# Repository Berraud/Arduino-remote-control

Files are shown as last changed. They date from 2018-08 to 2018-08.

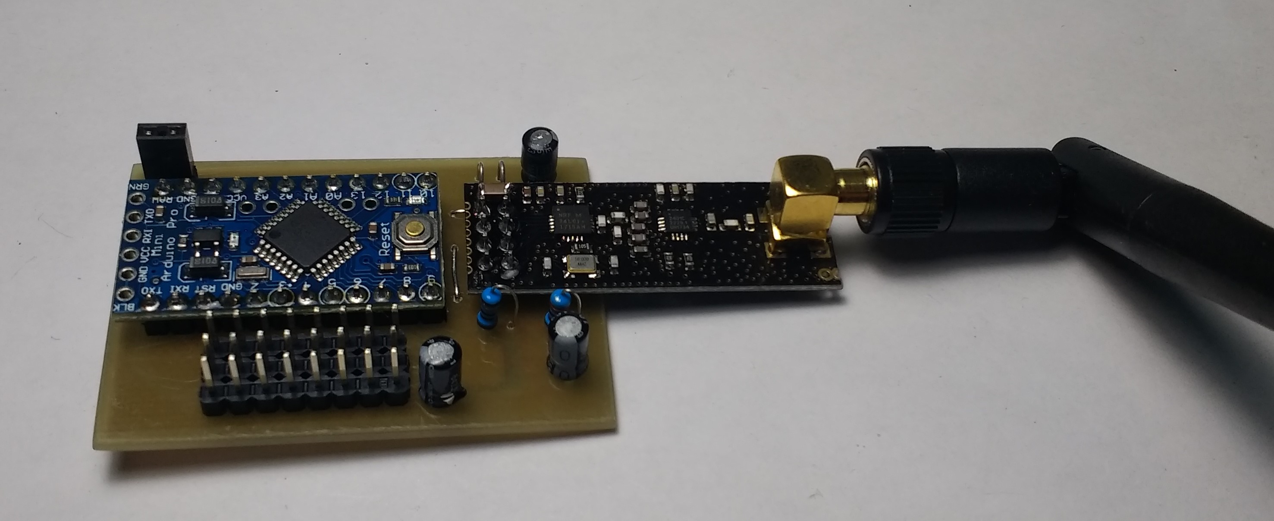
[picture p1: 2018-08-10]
PCB/RX.jpg

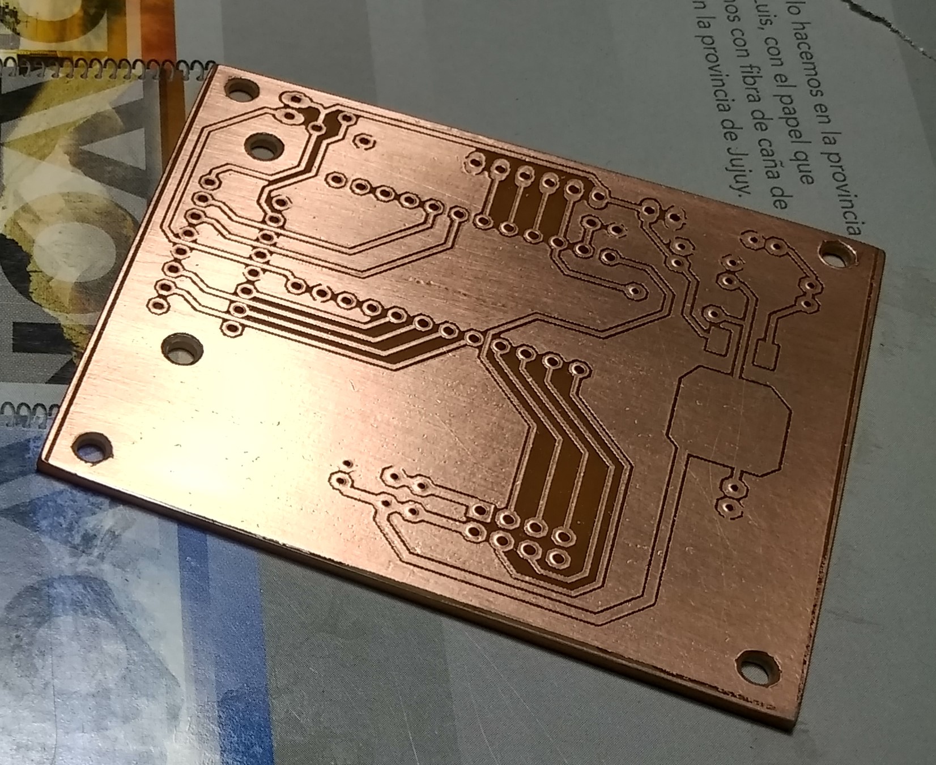
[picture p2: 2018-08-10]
PCB/Txb.jpg

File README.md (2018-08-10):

# Arduino-remote-control
Arduino based multi channel remote control for aeromodelism with telemetry and PS2 controller.
Based on arduino pro mini and NRF20L01 modules. Uses a PS2 remote controller as input.
Features multiple channels and memory for saving multiple models. Dual rates, throttle cut, on-fly default position set up (in case of signal lost), telemetry for measuring remote battery voltage and some other things.
If you have any questions email me to simonb2230@gmail.com

Based on a few nice projects from:
http://www.billporter.info/2010/06/05/playstation-2-controller-arduino-library-v1-0/
https://www.flitetest.com/articles/custom-arduino-2-4ghz-rc-transmitter
http://www.electronoobs.com/eng_robotica_tut5_2_1.php

and probably some other examples that I can't remember.

The power for the remote is from a single LiIon battery from a portable charger (using the same charging circuit)
The power for the receiver comes from the BEC of the ESC. The resistive divider on the receiver is calculated for a 3S Lipo battery.

The NRF modules need a 1uf ceramic SMD cap soldered directly on the PCB of the module itself

The range tested on ground is about 800m

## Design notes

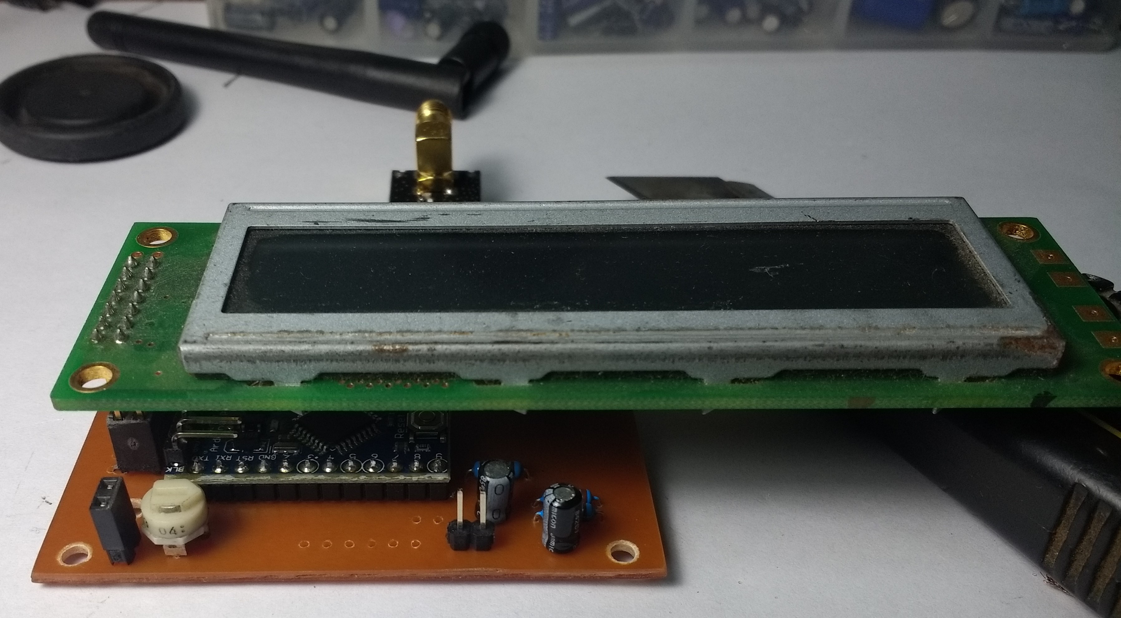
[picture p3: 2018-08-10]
PCB/Tx.jpg

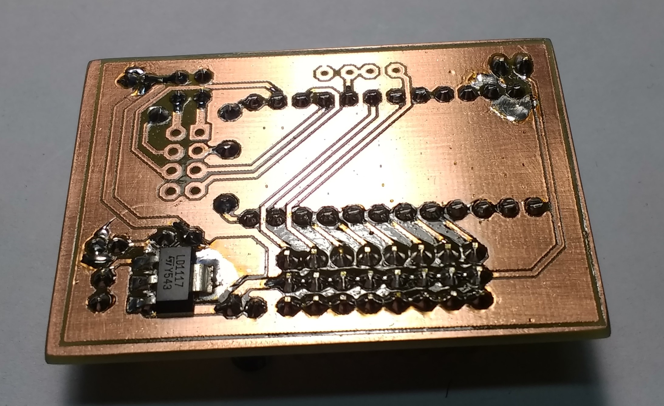
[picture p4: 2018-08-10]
PCB/RXb.jpg

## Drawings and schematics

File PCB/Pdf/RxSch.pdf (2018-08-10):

# ARDUINO-PRO-MINI-3.3V#SMP WIRELESS⁻NRF24L01⁻PA⁻EXT

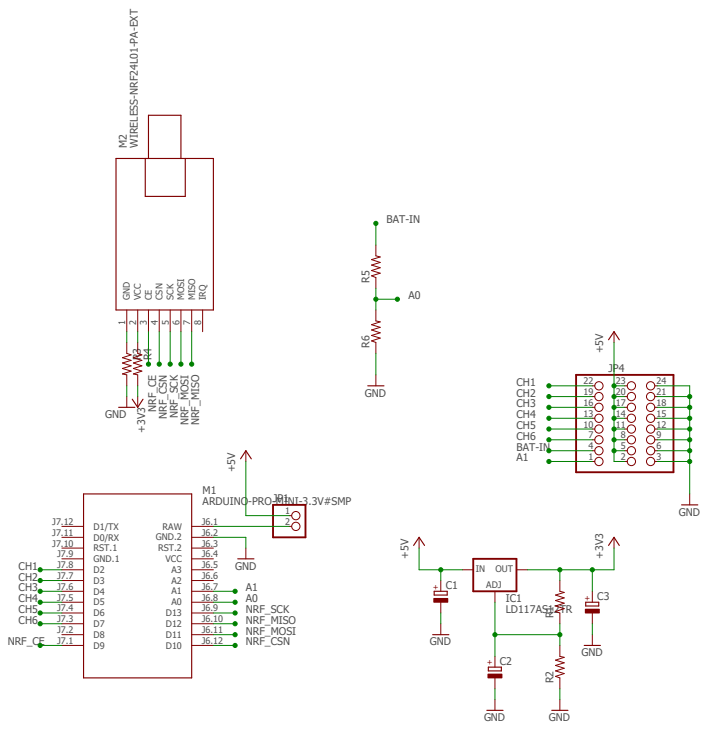
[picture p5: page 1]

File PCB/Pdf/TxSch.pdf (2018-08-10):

## 6 R¹ R²

# LED+

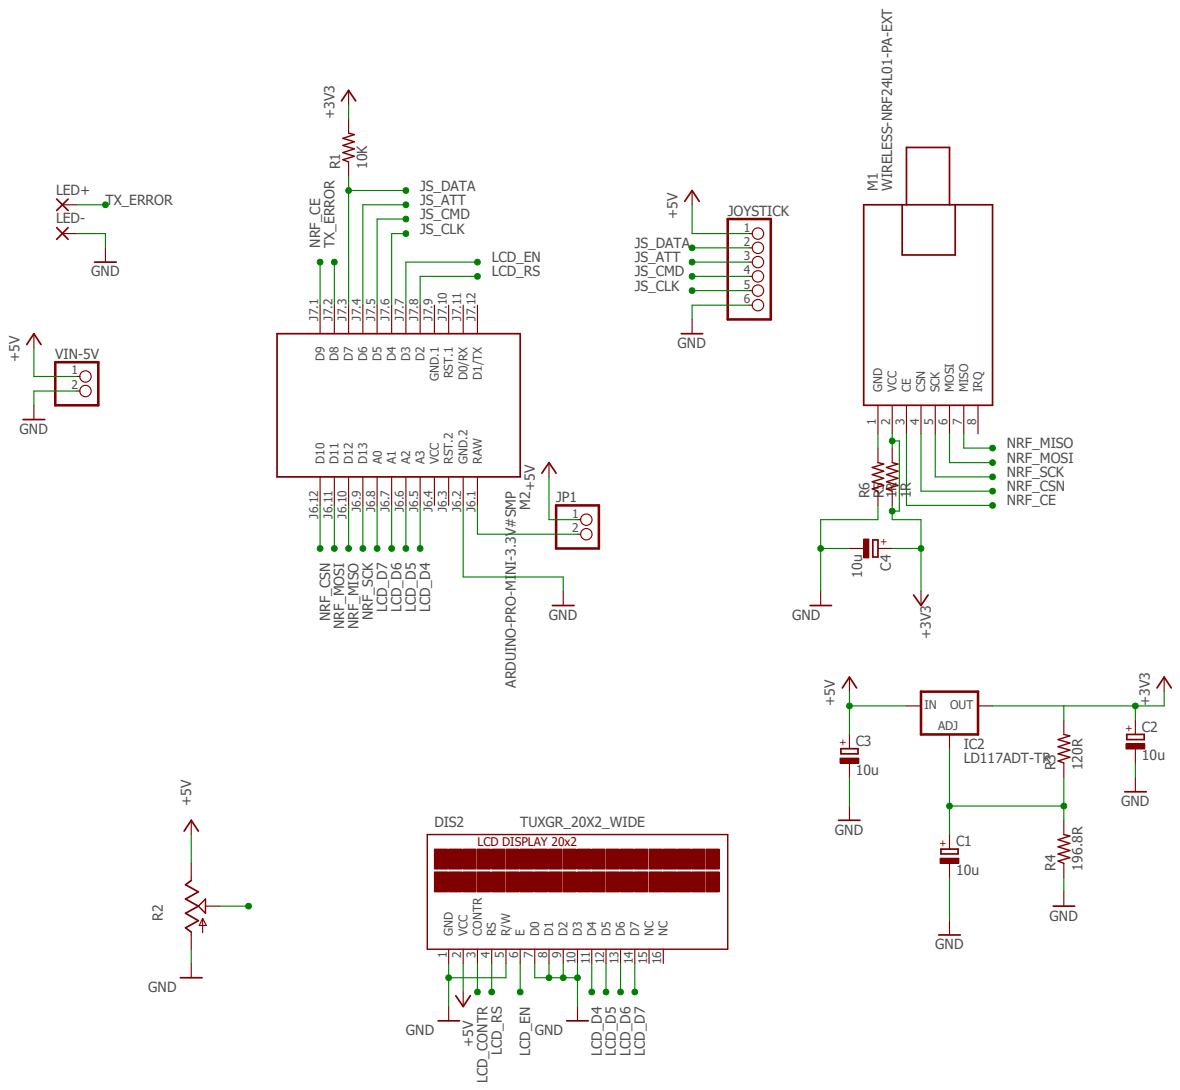
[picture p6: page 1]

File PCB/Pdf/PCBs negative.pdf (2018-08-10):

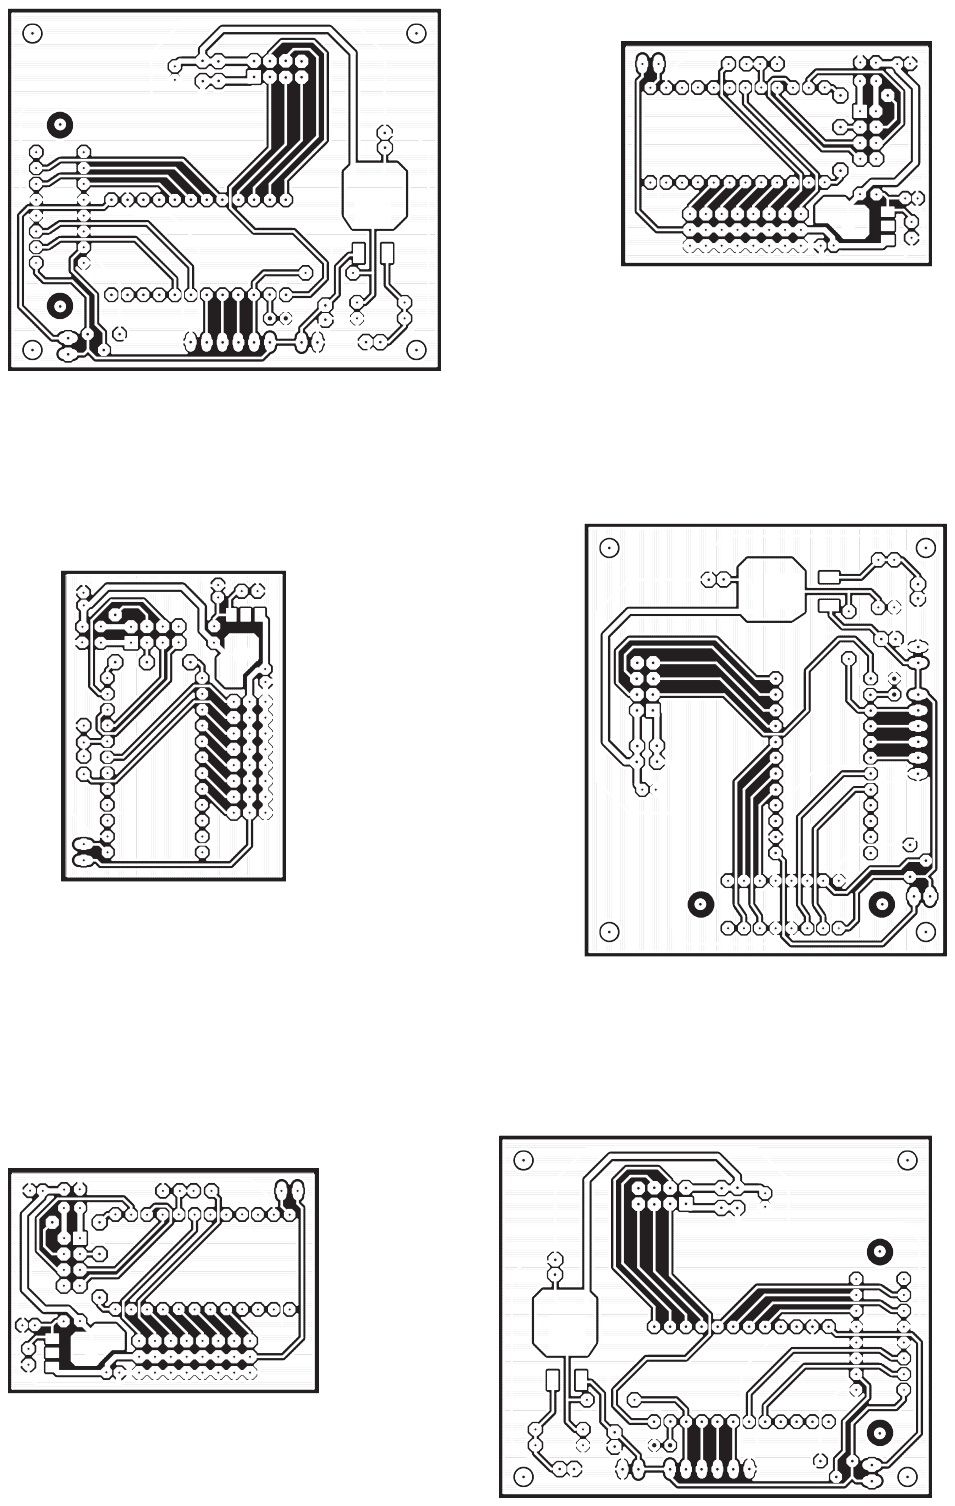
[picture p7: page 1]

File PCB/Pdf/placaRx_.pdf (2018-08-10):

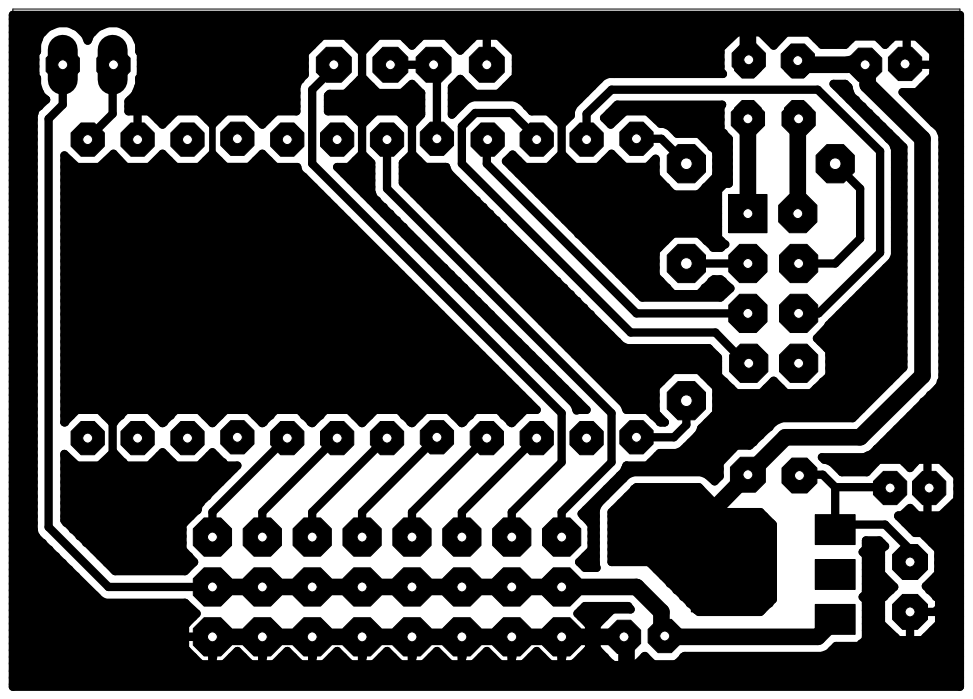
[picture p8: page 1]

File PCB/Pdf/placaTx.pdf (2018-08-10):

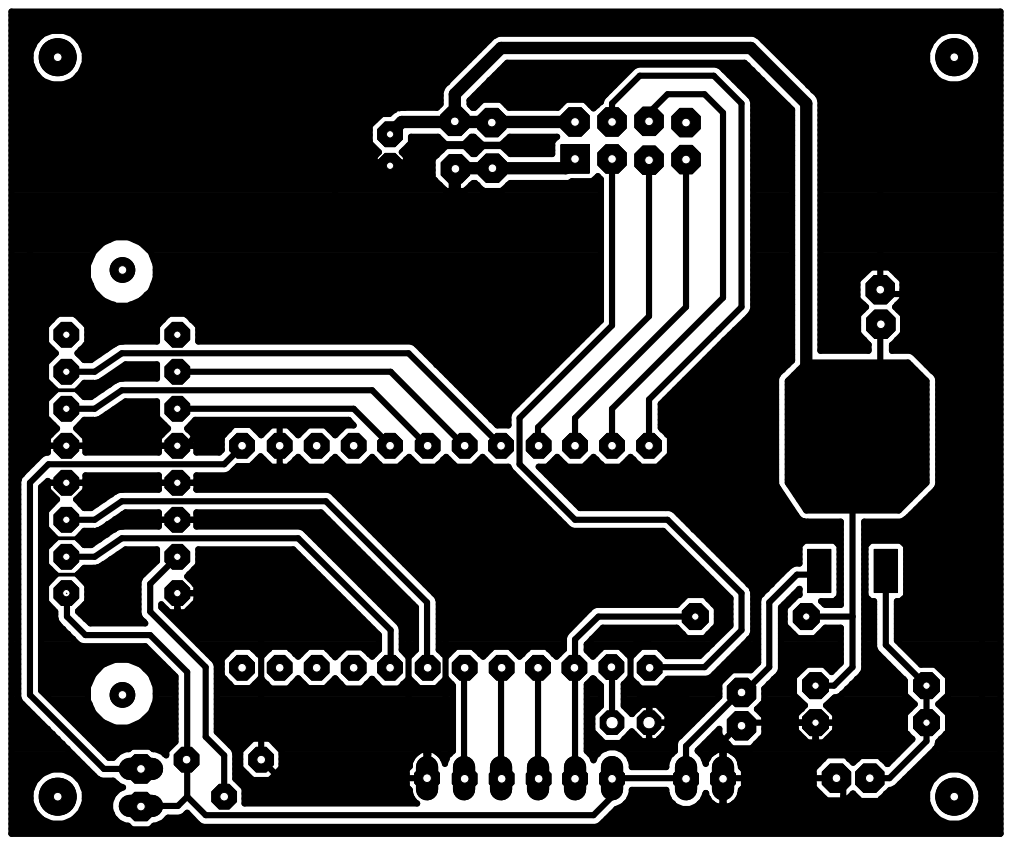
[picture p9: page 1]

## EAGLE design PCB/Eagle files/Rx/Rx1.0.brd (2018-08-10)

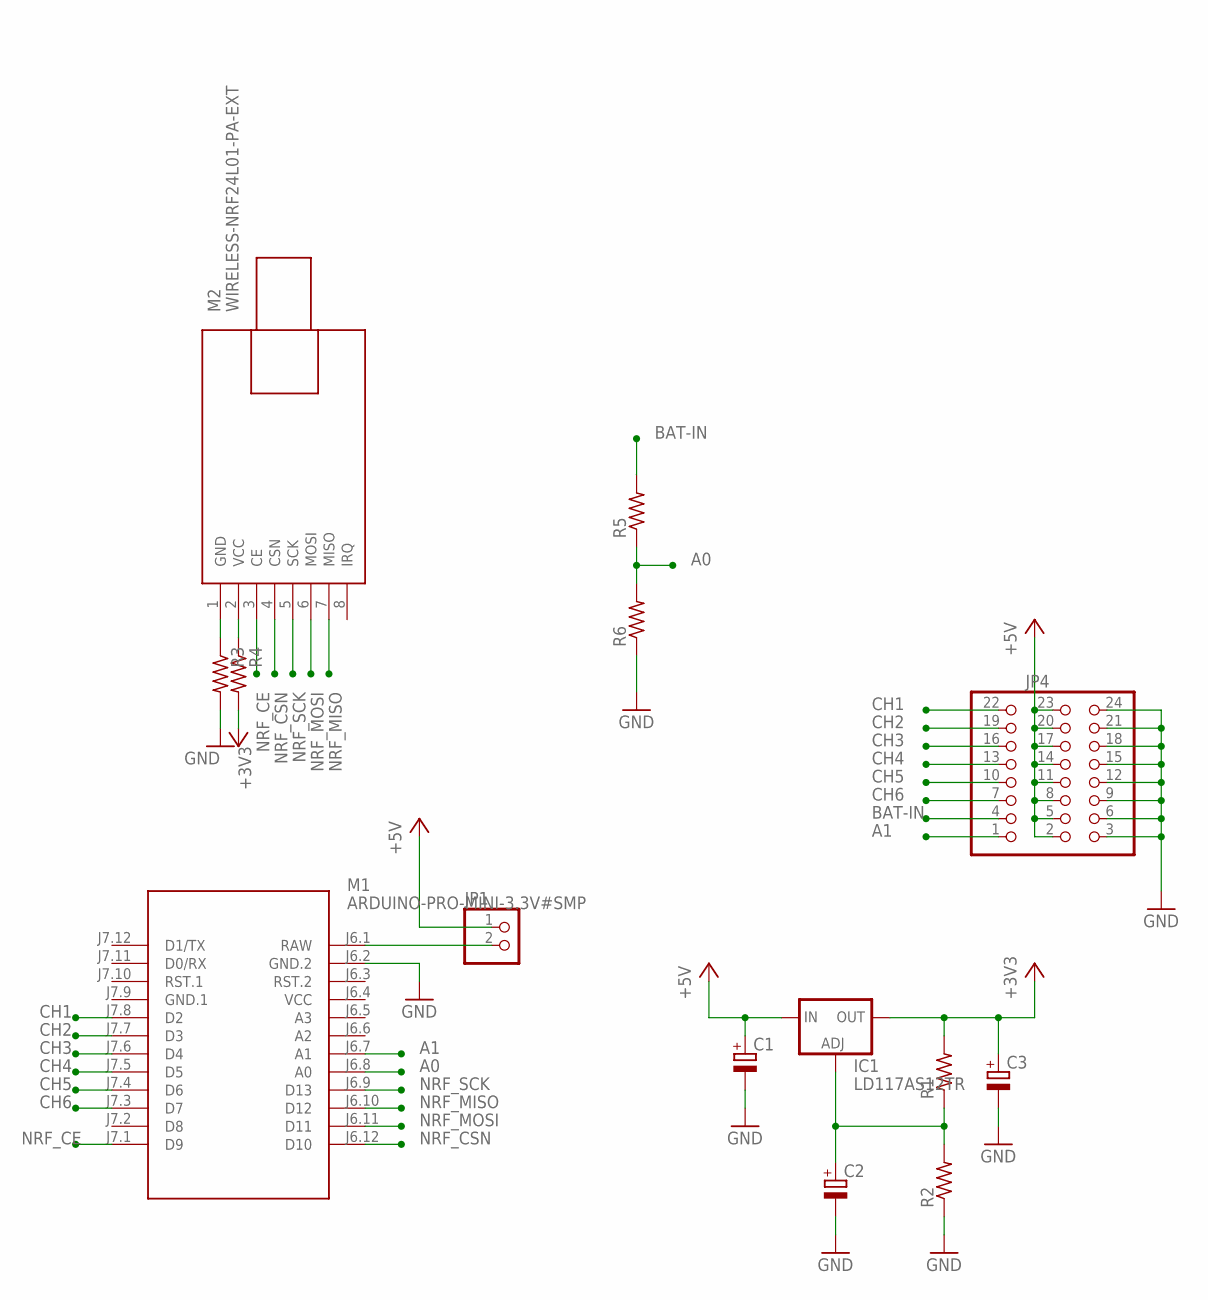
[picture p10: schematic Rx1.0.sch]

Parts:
C1, C2, C3: CPOL-EUE1.8-4; E1,8-4
IC1: LD117AS12TR; SOT223
JP1: PINHD-1X2; 1X02
JP4: PINHD-3X8; 2X08
M1: ARDUINO-PRO-MINI-3.3V#SMP; ARDUINO-PRO-MINI#SMP
M2: WIRELESS-NRF24L01-PA-EXT
R1, R2, R3, R4, R5, R6: R-US_0204/2V; 0204V

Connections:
+3V3: C3.+, IC1.4 (OUT), R1.2, R4.2
+5V: C1.+, IC1.3 (IN), JP1.1, JP4.2, JP4.5, JP4.8, JP4.11, JP4.14, JP4.17, JP4.20, JP4.23
A0: M1.J6.8 (A0), R5.1, R6.2
A1: JP4.1, M1.J6.7 (A1)
BAT-IN: JP4.4, R5.2
CH1: JP4.22, M1.J7.8 (D2)
CH2: JP4.19, M1.J7.7 (D3)
CH3: JP4.16, M1.J7.6 (D4)
CH4: JP4.13, M1.J7.5 (D5)
CH5: JP4.10, M1.J7.4 (D6)
CH6: JP4.7, M1.J7.3 (D7)
GND: C1.-, C2.-, C3.-, JP4.3, JP4.6, JP4.9, JP4.12, JP4.15, JP4.18, JP4.21, JP4.24, M1.J6.2 (GND.2), R2.1, R3.2, R6.1
GND.1: M1.J7.9 (GND.1)
unnamed: M2.1 (GND), R3.1
unnamed: M2.2 (VCC), R4.1
unnamed: C2.+, IC1.1 (ADJ), R1.1, R2.2
unnamed: JP1.2, M1.J6.1 (RAW)
NRF_CE: M1.J7.1 (D9), M2.3 (CE)
NRF_CSN: M1.J6.12 (D10), M2.4 (CSN)
NRF_MISO: M1.J6.10 (D12), M2.7 (MISO)
NRF_MOSI: M1.J6.11 (D11), M2.6 (MOSI)
NRF_SCK: M1.J6.9 (D13), M2.5 (SCK)
VCC: M1.J6.4 (VCC)

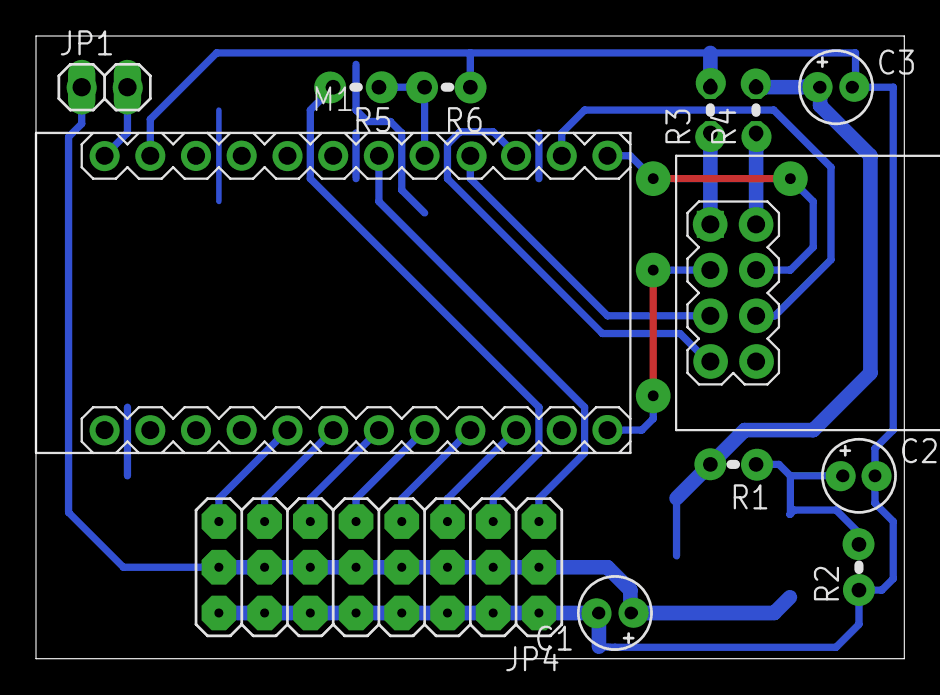
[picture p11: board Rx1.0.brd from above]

Board: 2 copper layers, 48.2 x 34.6 mm, 14 parts (1 on the bottom side), 21 nets.

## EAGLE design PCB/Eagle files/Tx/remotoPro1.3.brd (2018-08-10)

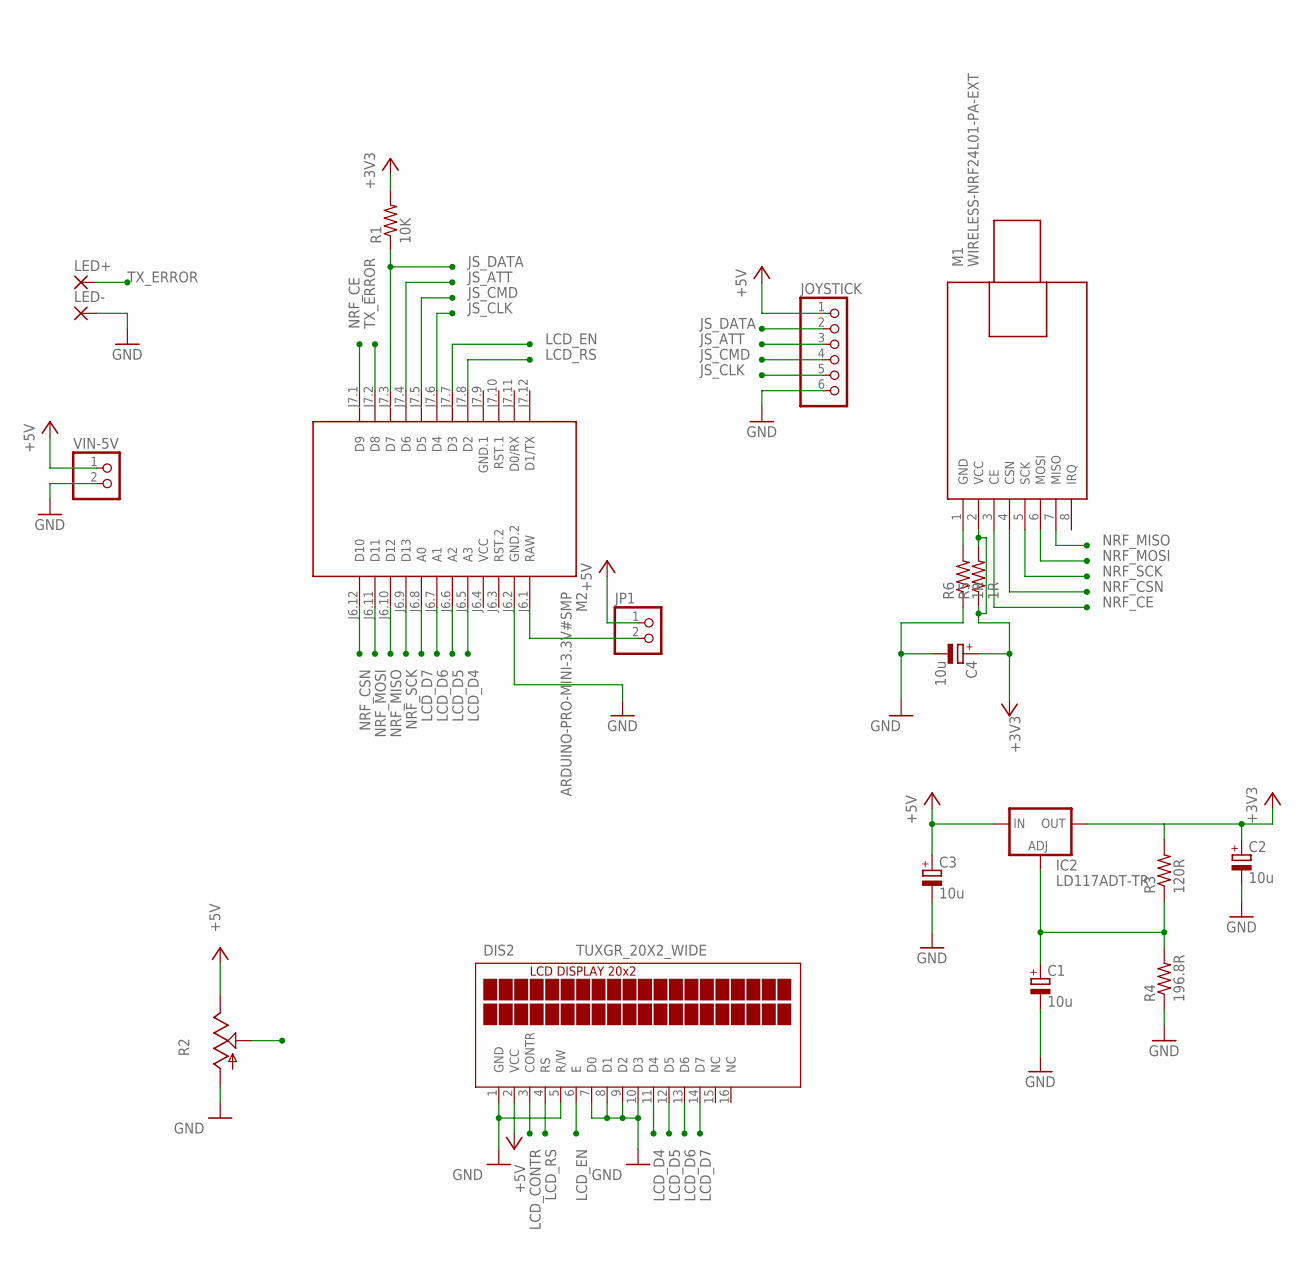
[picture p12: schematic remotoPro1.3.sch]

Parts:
C1, C2, C3, C4: 10u; E1,8-4
DIS2: TUXGR_20X2_WIDE
IC2: LD117ADT-TR; DPACK
JOYSTICK: PINHD-1X6; 1X06
JP1: PINHD-1X2; 1X02
LED+: 1,6/0,8
LED-: 1,6/0,8
M1: WIRELESS-NRF24L01-PA-EXT
M2: ARDUINO-PRO-MINI-3.3V#SMP; ARDUINO-PRO-MINI#SMP
R1: 10K; 0204/7
R2: TRIM_US-S75P; S75P
R3: 120R; 0204/7
R4: 196.8R; 0204/7
R5, R6: 1R; 0207/2V
VIN-5V: PINHD-1X2; 1X02

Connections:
+3V3: C2.+, C4.+, IC2.4 (OUT), M1.2 (VCC), R1.2, R3.2, R5.1, R5.2
+5V: C3.+, DIS2.2 (VCC), IC2.3 (IN), JOYSTICK.1, JP1.1, R2.E, VIN-5V.1
GND: C1.-, C2.-, C3.-, C4.-, DIS2.1 (GND), DIS2.5 (R/W), DIS2.7 (D0), DIS2.8 (D1), DIS2.9 (D2), DIS2.10 (D3), JOYSTICK.6, LED-.1, M2.J6.2 (GND.2), R2.A, R4.1, R6.1, VIN-5V.2
GND.1: M2.J7.9 (GND.1)
JS_ATT: JOYSTICK.3, M2.J7.4 (D6)
JS_CLK: JOYSTICK.5, M2.J7.6 (D4)
JS_CMD: JOYSTICK.4, M2.J7.5 (D5)
JS_DATA: JOYSTICK.2, M2.J7.3 (D7), R1.1
LCD_CONTR: DIS2.3 (CONTR), R2.S
LCD_D4: DIS2.11 (D4), M2.J6.5 (A3)
LCD_D5: DIS2.12 (D5), M2.J6.6 (A2)
LCD_D6: DIS2.13 (D6), M2.J6.7 (A1)
LCD_D7: DIS2.14 (D7), M2.J6.8 (A0)
LCD_EN: DIS2.6 (E), M2.J7.7 (D3)
LCD_RS: DIS2.4 (RS), M2.J7.8 (D2)
unnamed: JP1.2, M2.J6.1 (RAW)
unnamed: C1.+, IC2.1 (ADJ), R3.1, R4.2
unnamed: M1.1 (GND), R6.2
NRF_CE: M1.3 (CE), M2.J7.1 (D9)
NRF_CSN: M1.4 (CSN), M2.J6.12 (D10)
NRF_MISO: M1.7 (MISO), M2.J6.10 (D12)
NRF_MOSI: M1.6 (MOSI), M2.J6.11 (D11)
NRF_SCK: M1.5 (SCK), M2.J6.9 (D13)
TX_ERROR: LED+.1, M2.J7.2 (D8)
VCC: M2.J6.4 (VCC)

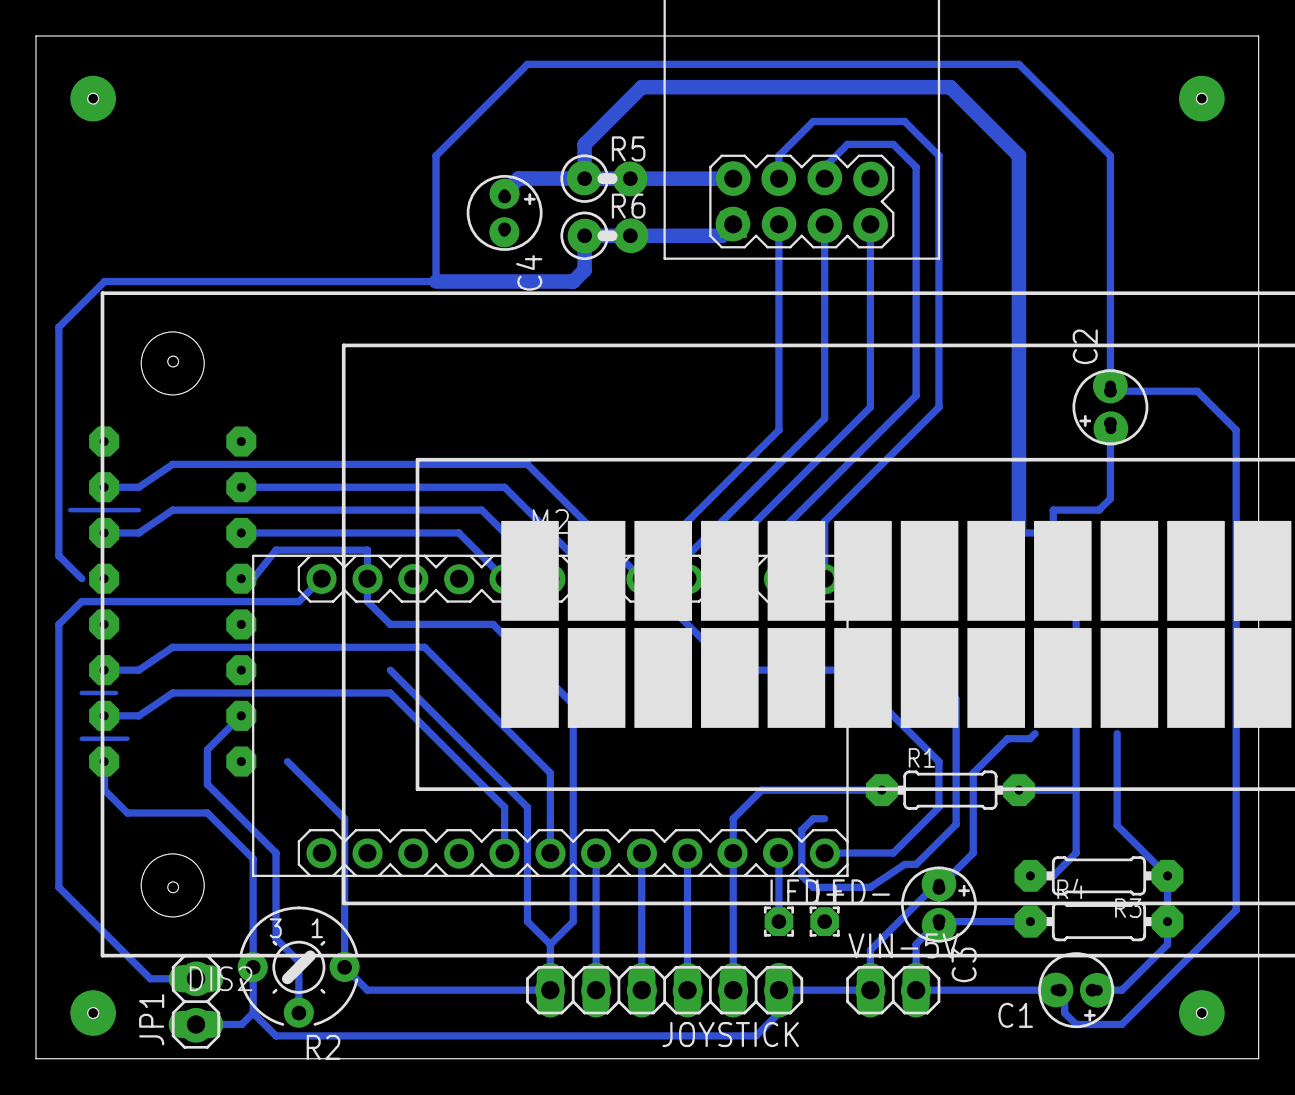
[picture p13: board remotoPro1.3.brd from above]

Board: 2 copper layers, 67.9 x 56.8 mm, 19 parts (1 on the bottom side), 23 nets.

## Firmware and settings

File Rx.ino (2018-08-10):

/* Receiver code for the Arduino Radio control with PWM output
 *  
 *  THIS ONLY WORKS WITH ATMEGA328p registers!!!!
 *  It gives a nice PWM output on pins D2, D3, D4, D5, D6 and D7. Still working on it...
 *  
 *  Install the NRF24 library to your IDE
 *  Import the servo library as well
 * Upload this code to the Arduino UNO
 * Connect a NRF24 module to it:
 
    Module // Arduino UNO
    
    GND    ->   GND
    Vcc    ->   3.3V
    CE     ->   D9
    CSN    ->   D10
    CLK    ->   D13
    MOSI   ->   D11
    MISO   ->   D12

This code receive 6 channels and create a PWM output for each one on D2, D3, D4, D5, D6 and D7
Please, like share and subscribe : https://www.youtube.com/c/ELECTRONOOBS
*/

#include <SPI.h>
#include <nRF24L01.h>
#include <RF24.h>
#include <Servo.h>

#include <EEPROM.h>

#define DEBUG

#ifdef DEBUG
 #define DEBUG_PRINT(x)    Serial.print (x)
 #define DEBUG_PRINTLN(x)  Serial.println (x)
#else
 #define DEBUG_PRINT(x)
 #define DEBUG_PRINTLN(x) 
#endif

//Define widths
int pwm_width_2 = 0;
int pwm_width_3 = 0;
int pwm_width_4 = 0;
int pwm_width_5 = 0;
int pwm_width_6 = 0;
int pwm_width_7 = 0;

Servo PWM2;
Servo PWM3;
Servo PWM4;
Servo PWM5;
Servo PWM6;
Servo PWM7;

                    //We could use up to 32 channels
struct MyData {
byte throttle;      //We define each byte of data input, in this case just 6 channels
byte yaw;
byte pitch;
byte roll;
byte AUX1;
byte AUX2;
};
MyData data;

//variable NRF24L01

const uint64_t pipes[2] = {0xE8E8F0F0E1LL,0xE8E8F0F0E2LL}; //IMPORTANT: The same as in the receiver
RF24 radio(9, 10); 

//Variables medición de batería

int BatTemp=0;
int loopbat=10;
byte Bateria=0;

//vector para almacenamiento en EEPROM
byte datosEEPROM[]={0,127,127,127};//inicializo con los valores que debería cargar en caso de que no haya nada, pero si hay algo los sobreescribo ni bien arranco
int i; //variable para recorrer vector y leer/escribir datos

void resetData()
{
//We define the inicial value of each data input
//3 potenciometers will be in the middle position so 127 is the middle from 254
data.throttle = datosEEPROM[0];
data.yaw = datosEEPROM[1];
data.pitch = datosEEPROM[2];
data.roll = datosEEPROM[3];
data.AUX1 = 0;
data.AUX2 = 0;
}

/**************************************************/

void setup()
{
  //Set the pins for each PWM signal
  PWM2.attach(2);
  PWM3.attach(3);
  PWM4.attach(4);
  PWM5.attach(5);
  PWM6.attach(6);
  PWM7.attach(7);

  analogReference(INTERNAL); // use the internal ~1.1volt reference
  #ifdef DEBUG
  Serial.begin(9600);
  #endif
  //Configure the NRF24 module
  
  resetData();
  radio.begin();
  //radio.setAutoAck(false);
  
  radio.enableAckPayload();                     // Allow optional ack payloads
  radio.enableDynamicPayloads();                // Ack payloads are dynamic payloads
  
  radio.setChannel(108);
  radio.setDataRate(RF24_250KBPS);  
  
  radio.openWritingPipe(pipes[0]);
  radio.openReadingPipe(1,pipes[1]);
  
  //we start the radio comunication
  radio.startListening();

  //valores por defecto EEPROM
  if (EEPROM.read(511)!=0) //si lo que haya en posición 511 (última) es distinto de 0 es que nunca escribí un dato válido, entonces inicializo
    {
     for( i=0 ; i<4 ; i++)
     {
      EEPROM.write(i,datosEEPROM[i]);  // dirección - dato
     }
    EEPROM.write(511,0);//y pongo en 0 la última posición para no pisar los valores la próxima vez que entre    
    }   
  else //si 511=0 es que tengo los datos que necesito en memoria, entonces los leo al vector
    {
    for( i=0 ; i<4 ; i++)
     {
     datosEEPROM[i] = EEPROM.read(i);  
     }
  }
}

/**************************************************/

unsigned long lastRecvTime = 0;

void recvData()
{
  //****
  byte pipeNo, gotByte;
  BatTemp+=analogRead(A0);
  loopbat--;
  if(loopbat==0)
    {
    loopbat=10;
    Bateria=(BatTemp/10)-768; //promedio 10 lecturas del ADC (no bloqueante) y después le resto 768 para que entre en 1 byte sin comprimir informacion
    DEBUG_PRINT(BatTemp/10);
    DEBUG_PRINT(" ");
    DEBUG_PRINTLN(Bateria);
    BatTemp=0;
    }
  while( radio.available(&pipeNo)){              // Read all available payloads
      radio.read(&data, sizeof(MyData));                  
      //Bateria=analogRead(A0);                                             // Since this is a call-response. Respond directly with an ack payload.
      //gotByte += 1;                                // Ack payloads are much more efficient than switching to transmit mode to respond to a call
      radio.writeAckPayload(pipeNo,&Bateria, 1 );  // This can be commented out to send empty payloads.
      //DEBUG_PRINT(F("Loaded next response "));
      //DEBUG_PRINTLN(Bateria);  
      lastRecvTime = millis(); //here we receive the data
   }

}

void writeDefault()
{
//en la variable datosEEPROM siempre tengo lo que tengo que pasar a los servos en caso de pérdida de señal
datosEEPROM[0]=data.throttle;
datosEEPROM[1]=data.yaw;
datosEEPROM[2]=data.pitch;
datosEEPROM[3]=data.roll;

for( i=0 ; i<4 ; i++) //guardo la nueva posición por defecto en la EEPROM
     {
      EEPROM.write(i,datosEEPROM[i]);  // dirección - dato
     }
}

/**************************************************/

void loop()
{
recvData();
unsigned long now = millis();

//Here we check if we've lost signal, if we did we reset the values 

if ( now - lastRecvTime > 1000 ) // Signal lost?
  {
  resetData();
  }

if(now - lastRecvTime > 120000) //si perdí la señal por 2 minutos pongo los valores para que caiga
  {//los pongo directo acá por que si bien también va a entrar el if anterior y va a poner los valores por defecto este los va a sobreescribir y la idea es que acá no entre nunca
    //la pérdida de procesamiento va a ser menor que revisando en cada vuelta que sea mayor a 1000 y menor a 120.000
  data.throttle=0; //apagar motor
  data.yaw = 0; //todo para la izquierda con la cola
  data.pitch = 255; //todo para abajo con elevador
  data.roll = 127;
    
  }

//verifico si recibí la orden de escribir valores por defecto nuevos en EEPROM
if(data.AUX2==255)
  writeDefault();

pwm_width_2 = map(data.throttle, 0, 255, 1000, 2000);     //PWM value on digital pin D2
pwm_width_3 = map(data.yaw,      0, 255, 1000, 2000);     //PWM value on digital pin D3
pwm_width_4 = map(data.pitch,    0, 255, 1000, 2000);     //PWM value on digital pin D4
pwm_width_5 = map(data.roll,     0, 255, 1000, 2000);     //PWM value on digital pin D5
pwm_width_6 = map(data.AUX1,     0, 255, 1000, 2000);     //PWM value on digital pin D6
pwm_width_7 = map(data.AUX2,     0, 255, 1000, 2000);     //PWM value on digital pin D7


//Now we write the PWM signal using the servo function
PWM2.writeMicroseconds(pwm_width_2);
PWM3.writeMicroseconds(pwm_width_3);
PWM4.writeMicroseconds(pwm_width_4);
PWM5.writeMicroseconds(pwm_width_5);
PWM6.writeMicroseconds(pwm_width_6);
PWM7.writeMicroseconds(pwm_width_7);


}//Loop end
/**************************************************/

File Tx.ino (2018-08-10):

#include <LiquidCrystal.h>
#include <EEPROM.h>

//comunicación
#include <SPI.h>
#include <nRF24L01.h>
#include <RF24.h>
/*
 * Versión 1.8 - Agregado guardar en EEPROM posición por defecto ante pérdida de señal
 * 
 */

 /*
  * Librerías EEPROM
  * Cuando el canal "AUX2" se pone en 255 detecta que esa es la posición que debe guardar, copia valores en vector temporal? y llama a función
  * que escriba EEPROM
  * Por defecto arranca leyendo la EEPROM y si no hay un valor válido guarda todo centrado
  */
//Librerías Joystick
#include <PS2X_lib.h>  //for v1.6
PS2X ps2x; // create PS2 Controller Class

//#define DEBUG //descomentar esta linea para activar los serialprint

#ifdef DEBUG
 #define DEBUG_PRINT(x)    Serial.print (x)
 #define DEBUG_PRINTLN(x)  Serial.println (x)
#else
 #define DEBUG_PRINT(x)
 #define DEBUG_PRINTLN(x) 
#endif

#define CHANNELS 4
#define SWITCHES 2
#define MODELOS 5
#define CANALTH 0

#define swTC 0
#define swDR 1

#define eepromModeloId 0;

//variables joystick
int js_error = 0; 
byte js_type = 0;
byte vibrate = 0;//Variable para vibración del joystick. No se usa en esta versión

//variables comunicación
/*Create a unique pipe out. The receiver has to 
  wear the same unique code*/
  
const uint64_t pipes[2] = {0xE8E8F0F0E1LL,0xE8E8F0F0E2LL}; //IMPORTANT: The same as in the receiver
//2 pipes. Una para emitir los datos y otra para recibir el ack con la información de telemetría
RF24 radio(9, 10); // select  CSN  pin

uint16_t g_input[CHANNELS];

// canales del TX
int menuActual=0;

unsigned char modelo_actual=0;  // id del modelo actual
unsigned char num_menus=5; // numOpciones-1
unsigned char submenu_actual=0;  // para cuando este dentro del menu
unsigned char servo_reversa[MODELOS];
unsigned char servo_reversa_cambio=0;
unsigned char estado_display=0;  // variable para el refresco del display

unsigned char canal_cambio=0;  // variable para seleccion de canal en los submenus

unsigned char canal_cambio_dr=0;
unsigned char dual_rate_low[MODELOS][CHANNELS];
unsigned char dual_rate_hi[MODELOS][CHANNELS];

// valores varios
int potenciometros[CHANNELS];  // lectura de potenciometros
unsigned char sw_status=0x00;    //0:TC 1:DR  2:EXPO 
int potMin = 0;
int potMax = 255;

byte Bateria=0; //esta variable es la que uso para recibir el dato
int BateriaLocal=0; //para leer el ADC local
bool bat=0; //indica qué batería hay que mostrar. 0 es remota
char Str[6]=" ";//en esta lo guardo formateado para mostrar
float BatDec=0;//esta es para pasar el valor de lectura a una tensión 

int Ping=0;

int esperar=0;

//variables de estado para entradas
bool EstadoUp=0;
bool EstadoDown=0;
bool EstadoLeft=0;
bool EstadoRight=0;
bool EstadoSelect=0;
bool EstadoL2=0; //Throtle Cut
bool EstadoTriangulo=0; //si aprieto triángulo el receptor guarda por defecto ante pérdida de señal los valores actuales
                        //la idea es poner el avión a dar vueltas y apretarlo, cosa de que después haga solito lo mismo
bool EstadoTC=1;
bool EstadoR2=0; //Dual rates
bool EstadoR1=0; //Bateria local o remota
bool EstadoDR=1;
// LCD
LiquidCrystal lcd(2, 3, 17, 16, 15, 14); //RS-A5/EN-A4/D4-A3/D5-A2/D6-A1/D7-A0

//***********************************************************************ESTRUCTURAS**********************************************************************


// mensajes del menu
char msgs[6][17] = {
  "Menu        ",
  "1.Servo Dir.", 
  "2.Dual Rates", 
  "3.E.P.A.    ", 
  "4.Guardar   ", 
  "5.Modelo    " };

byte lcdChar[][8] = { 
  {
  0x00,
  0x00,
  0x00,
  0x00,
  0x00,
  0x00,
  0x00,
  0x1F},
  
  {
  0x00,
  0x00,
  0x00,
  0x00,
  0x00,
  0x00,
  0x1F,
  0x00},
  
  {
  0x00,
  0x00,
  0x00,
  0x00,
  0x00,
  0x1F,
  0x00,
  0x00},
  
  {
  0x00,
  0x00,
  0x00,
  0x00,
  0x1F,
  0x00,
  0x00,
  0x00},
  
  {
  0x00,
  0x00,
  0x00,
  0x1F,
  0x00,
  0x00,
  0x00,
  0x00},
  
  {
  0x00,
  0x00,
  0x1F,
  0x00,
  0x00,
  0x00,
  0x00,
  0x00},
  
  {
  0x00,
  0x1F,
  0x00,
  0x00,
  0x00,
  0x00,
  0x00,
  0x00},
  
  {
  0x1F,
  0x00,
  0x00,
  0x00,
  0x00,
  0x00,
  0x00,
  0x00}
  
} ;
// /LCD

//Estrucura comunicación
// The sizeof this struct should not exceed 32 bytes
// This gives us up to 32 8 bits channals
struct MyData {
  byte throttle;
  byte yaw;
  byte pitch;
  byte roll;
  byte AUX1;
  byte AUX2;
};

MyData data;


//***********************************************************************FUNCIONES**********************************************************************

void resetData() 
{
  //This are the start values of each channal
  // Throttle is 0 in order to stop the motors
  //127 is the middle value of the 10ADC.
    
  data.throttle = 0;
  data.yaw = 127;
  data.pitch = 127;
  data.roll = 127;
  data.AUX1 = 0;
  data.AUX2 = 0;
}

int ajusteValor(int maximo, int minimo, int valor) {
  int salida;
  float divisor;
  divisor=255.0/(maximo-minimo);
  salida=valor/divisor;
  return salida;
}

int ajusteDR(int valor, int dr, int canal) {
  int salida,temp;
  float mult;
  int canalth=CANALTH;
  
  if (canal==canalth) {
    // dual rate del total
    mult=dr/100.0;
    salida=valor*mult;  
  } else {
     // dual rate de los extremos
     temp=valor-127;
     mult=dr/100.0;
     salida=(temp*mult)+127;
     
  }
  
  return salida;
}
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

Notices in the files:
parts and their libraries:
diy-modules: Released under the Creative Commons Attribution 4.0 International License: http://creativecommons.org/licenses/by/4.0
